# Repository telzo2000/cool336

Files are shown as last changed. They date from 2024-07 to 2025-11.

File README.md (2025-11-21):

# cool336

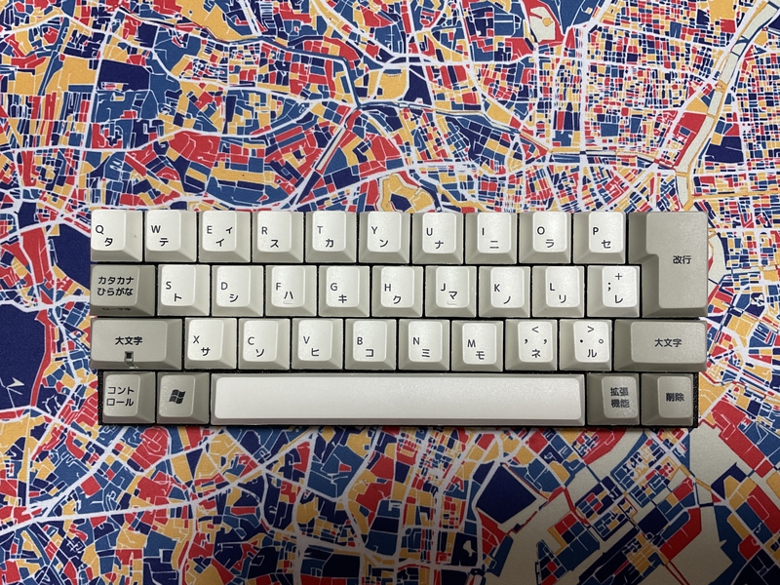
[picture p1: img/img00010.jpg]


## What is cool336?

Do you have an unused ISO enter key or 7U space key in a corner of your room?
<br>
部屋の隅に未使用の ISO エンターキーや 7U スペースキーはありませんか?
<br>
<br>
cool336 is qaz layout keyboard.
<br>
cool336はqaz配列のキーボードです。
<br><br>
cool336 has a iso enter key and 7U long space key.
<br>
cool336 には ISO Enter キーと 7U の長いスペースキーがあります。
<br>
PCV ver1.2で７Uスペースバーを３Ux2、１Ux1の三分割スペースバーの選択ができるようになりました。
<br>

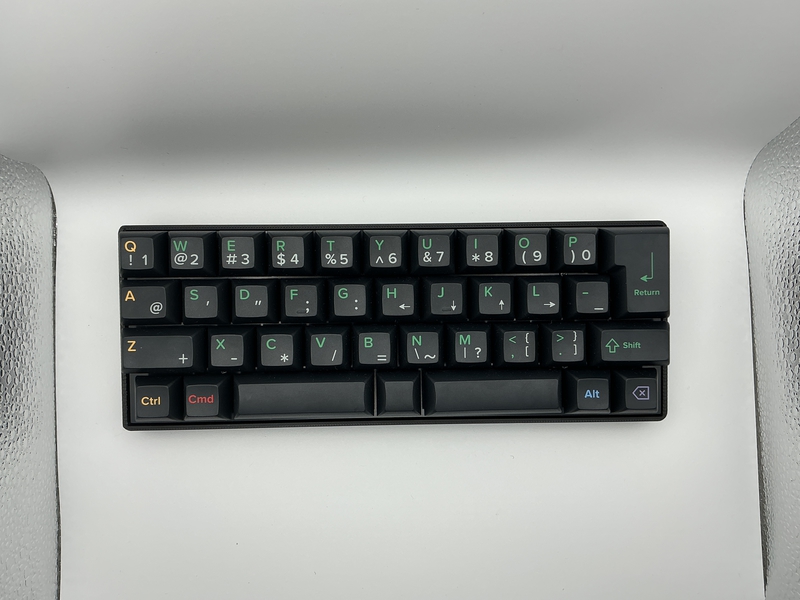
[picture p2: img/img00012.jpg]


# Layout

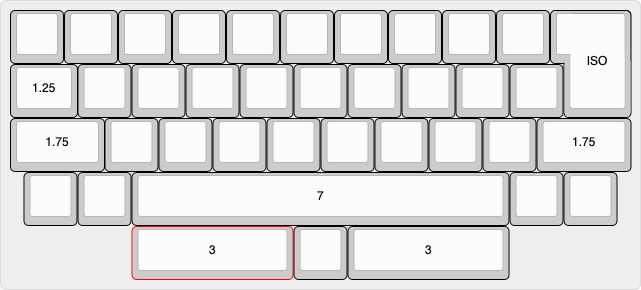
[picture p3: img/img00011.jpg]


## How to get keycaps?

https://yuzukeycaps.com/keyboards/cool336ble

## firmware 

cool336 use RP2040-Zero,run qmk_firware.
<br>
cool336 は RP2040-Zero を使用し、qmk_firware を実行します。
<br><br>

## build

### summary
1 Diode soldering
<br>
2 Switch socket soldering
<br>
3 RP2040-Zero and conthrough soldering
<br>
4 Install firmware
<br>
5 Fix thestabilizer
<br>
6 Fix the switch plate with screws
<br>
7 Insert the key switch
<br>
8 Fix the bottom plate with screws.
<br>
9 Complete
<br>

https://github.com/telzo2000/cool336/blob/main/buildguide_for_cool336.md

## Parts list

For PCB Ver.1.0
| No. | Patrs | Quantity | remarks | Suppliers | Cost |
|--|--|--|--|--|--|
|番号|名前|数|備考|調達先|参考価格（送料込）|<br>
|1|PCB|1|36key|[elecrow](https://www.elecrow.com)<br>[JLCPCB](https://jlcpcb.com)<br>[ALLPCB](https://www.allpcb.com)|５枚で20〜30ドル|<br>
|2|RP-2040Zero|1|MCU Board|[Talp Keyboard](https://talpkeyboard.net)|420円|
|3|Swith socket<br>スイッチソケット|36|cherry MX互換|[遊舎工房](https://yushakobo.jp)<br>[Talp Keyboard](https://talpkeyboard.net)<br>[Daily Craft Keyboard](https://shop.dailycraft.jp)等|10個で165円程度|
|3|Diode<br>ダイオード|36|リードタイプでもSMDでも可|[遊舎工房](https://yushakobo.jp)<br>[Talp Keyboard](https://talpkeyboard.net)<br>[Daily Craft Keyboard](https://shop.dailycraft.jp)等|100個で220円程度から|
|4a|Switch plate|1|3D Print|||
|4b|Switch plate|1|Acrylic,with M2 Spacer 3mm x4|[elecrow](https://www.elecrow.com/acrylic-cutting.html)|5枚で９ドル程度（送料込み）|
|5|Bottom plate|1|3D Print||
|6|Screw<br>ネジ|4|M2 8mm|DIY shop|10本200円程度|
|7|Screw<br>ネジ|4|M2 4mm|DIY shop|10本200円程度|
|8|Spacer<br>スペーサー|4|M2 3mm|DIY shop|10本400円程度|
|9|Stabilizer<br>スタビライザー|2|2Ux1,7Ux1|[遊舎工房](https://yushakobo.jp)<br>[Talp Keyboard](https://talpkeyboard.net)|セットで2000円程度|
|10|Conthrou<br>コンスルー|2|3.5mm|[遊舎工房](https://yushakobo.jp)<br>[Talp Keyboard](https://talpkeyboard.net)|１個400円程度|
|11|Keyswitch<br>キースイッチ|36|お好みで|[遊舎工房](https://yushakobo.jp)<br>[Talp Keyboard](https://talpkeyboard.net)<br>[Daily Craft Keyboard](https://shop.dailycraft.jp)|１個100程度|
|12|Keycap<br>キーキャップ|36|1Ux31、1.25Ux2、1.75Ux2、7Ux1|[遊舎工房](https://yushakobo.jp)<br>[Talp Keyboard](https://talpkeyboard.net)<br>[Daily Craft Keyboard](https://shop.dailycraft.jp)||

For PCB Ver.1.2
| No. | Patrs | Quantity | remarks | Suppliers | Cost |
|--|--|--|--|--|--|
|番号|名前|数|備考|調達先|参考価格（送料込）|<br>
|1|PCB|1|36key|[elecrow](https://www.elecrow.com)<br>[JLCPCB](https://jlcpcb.com)<br>[ALLPCB](https://www.allpcb.com)|５枚で20〜30ドル|<br>
|2|RP-2040Zero|1|MCU Board|[Talp Keyboard](https://talpkeyboard.net)|420円|
|3|Swith socket<br>スイッチソケット|36~38|cherry MX互換|[遊舎工房](https://yushakobo.jp)<br>[Talp Keyboard](https://talpkeyboard.net)<br>[Daily Craft Keyboard](https://shop.dailycraft.jp)等|10個で165円程度|
|3|Diode<br>ダイオード|36~38|リードタイプでもSMDでも可|[遊舎工房](https://yushakobo.jp)<br>[Talp Keyboard](https://talpkeyboard.net)<br>[Daily Craft Keyboard](https://shop.dailycraft.jp)等|100個で220円程度から|
|4|Switch plate|1|FR-4|[elecrow](https://www.elecrow.com)<br>[JLCPCB](https://jlcpcb.com)<br>[ALLPCB](https://www.allpcb.com)|５枚で20〜30ドル|
|5|Bottom Case|1|3D Print||
|6|Screw<br>ネジ|8|M2 6mm|DIY shop|10本200円程度|
|7|Spacer<br>スペーサー|4|M2 10mm|DIY shop|10本400円程度|
|8|Stabilizer<br>スタビライザー|2~3|2Ux1,7Ux1or3Ux2|[遊舎工房](https://yushakobo.jp)<br>[Talp Keyboard](https://talpkeyboard.net)|セットで2000円程度|
|10|Conthrou<br>コンスルー|2|3.5mm|[遊舎工房](https://yushakobo.jp)<br>[Talp Keyboard](https://talpkeyboard.net)|１個400円程度|
|11|Keyswitch<br>キースイッチ|36^38|お好みで|[遊舎工房](https://yushakobo.jp)<br>[Talp Keyboard](https://talpkeyboard.net)<br>[Daily Craft Keyboard](https://shop.dailycraft.jp)|１個100程度|
|12|Keycap<br>キーキャップ|36|1Ux31~32、1.25Ux2、1.75Ux2、7Ux1or3Ux2|[遊舎工房](https://yushakobo.jp)<br>[Talp Keyboard](https://talpkeyboard.net)<br>[Daily Craft Keyboard](https://shop.dailycraft.jp)||

In addition, you will need a USB cable, etc.
<br>
この他に、USBケーブル等が必要です。
<br>

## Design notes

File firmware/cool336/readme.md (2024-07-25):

# cool336

cool336

*A short description of the keyboard/project*

* Keyboard Maintainer: [m.ki](https://github.com/telzo2000)
* Hardware Supported: *The PCBs, controllers supported*
* Hardware Availability: *Links to where you can find this hardware*

Make example for this keyboard (after setting up your build environment):

    make cool336:default

Flashing example for this keyboard:

    make cool336:default:flash

See the [build environment setup](https://docs.qmk.fm/#/getting_started_build_tools) and the [make instructions](https://docs.qmk.fm/#/getting_started_make_guide) for more information. Brand new to QMK? Start with our [Complete Newbs Guide](https://docs.qmk.fm/#/newbs).

## Bootloader

Enter the bootloader in 3 ways:

* **Bootmagic reset**: Hold down the key at (0,0) in the matrix (usually the top left key or Escape) and plug in the keyboard
* **Physical reset button**: Briefly press the button on the back of the PCB - some may have pads you must short instead
* **Keycode in layout**: Press the key mapped to `QK_BOOT` if it is available

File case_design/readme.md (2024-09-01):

# About Case_design

cool336は大きく５つのパターンのケースデザインがあります。

１　3Dプリンタのスイッチプレートと3Dプリンタのボトムプレート

２　3Dプリンタのスイッチプレートと3Dプリンタのボトムケース

３　3Dプリンタのトップケースと3Dプリンタのボトムプレート

４　アクリルのスイッチプレートと3Dプリンタのボトムプレート

５　アクリルのスイッチプレートと3Dプリンタのボトムケース

１は最初に考えたサンドイッチマウントのケースです。

２はボトムプレートを修正してトレー型にしたケースです。

１及び２は[booth](https://booth.pm/ja/items/5953728)で頒布しています。

３は実験的に作ったものです。底面の合わせ目のデザインの解決がなく、使用していません。

４及び５は3Dプリントのスイッチプレートの柔らかさが気になるかなと思い、アクリルで製作したものです。[キーフリ[(https://connpass.com/event/314453/)で頒布予定です。

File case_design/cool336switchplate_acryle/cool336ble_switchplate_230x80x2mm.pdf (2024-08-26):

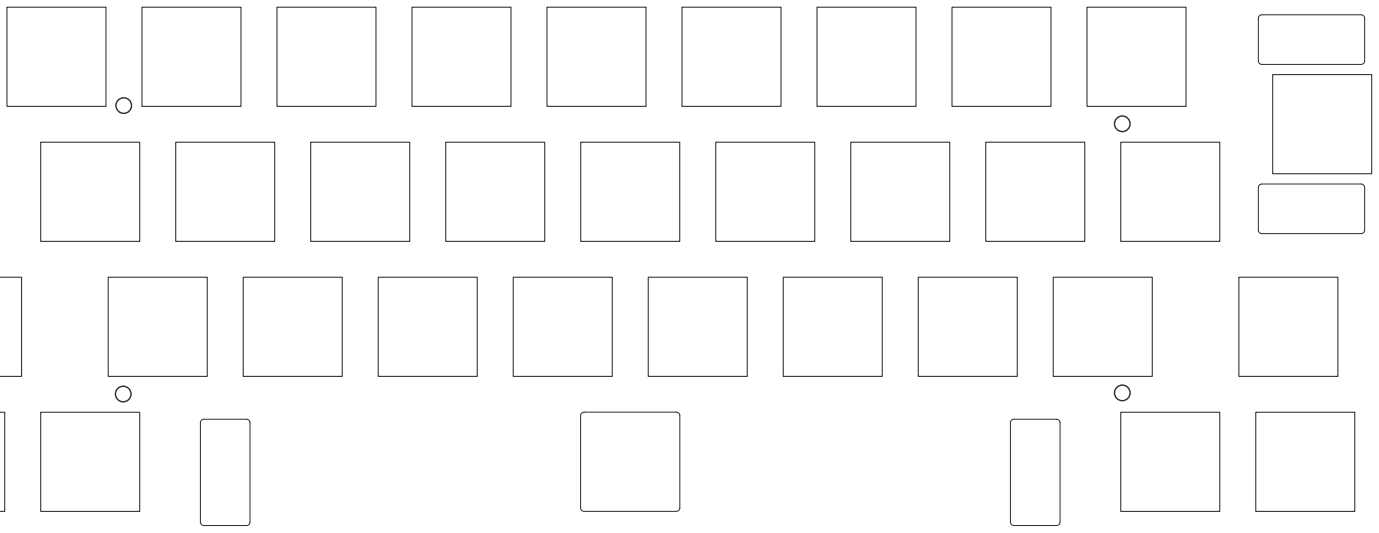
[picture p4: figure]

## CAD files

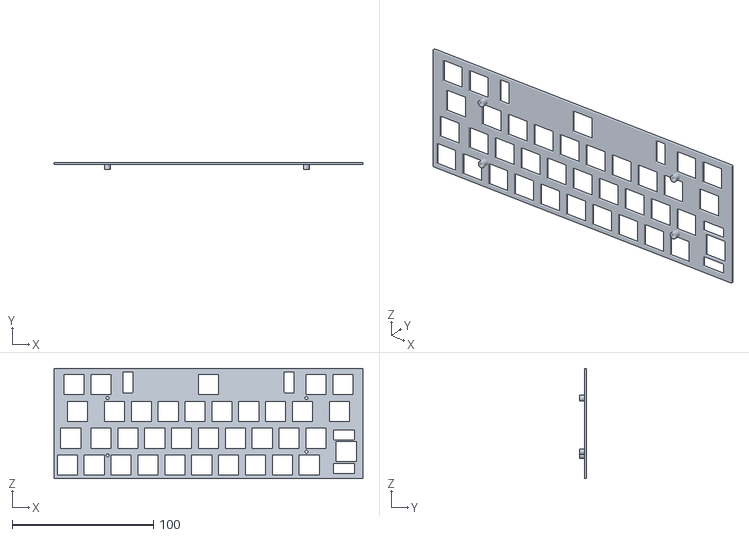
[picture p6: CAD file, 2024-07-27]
case_design/3Dprint/cool336_switchplate v6.stl
219.0 x 5.00 x 78.0

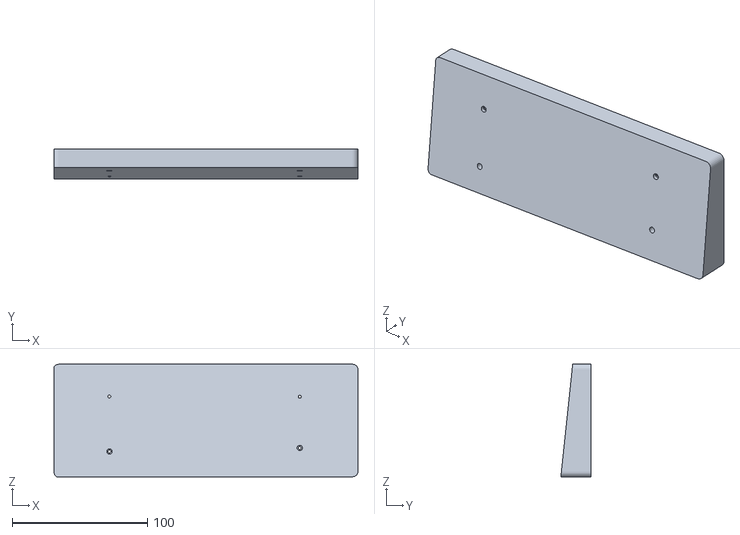
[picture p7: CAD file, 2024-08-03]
case_design/another_bottomcase_design/cool336_case_design_bottom v6.stl
225.0 x 22.4 x 83.4

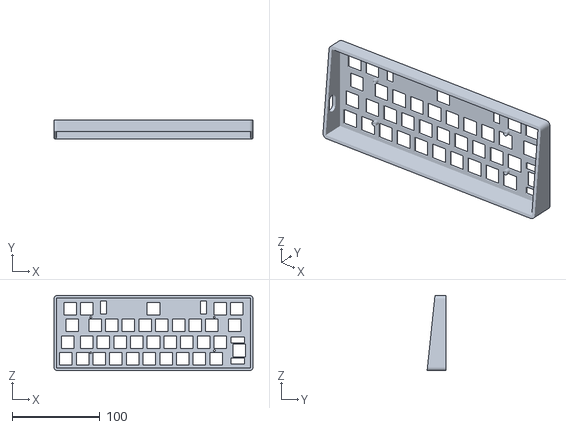
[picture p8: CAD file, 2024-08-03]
case_design/another_topcase_design/cool336_case_design v2.stl
227.0 x 21.5 x 86.0

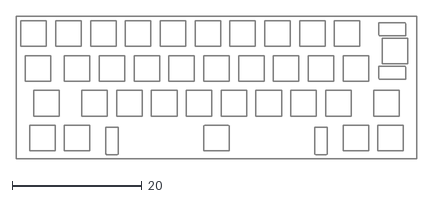
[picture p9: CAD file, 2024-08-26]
case_design/cool336switchplate_acryle/cool336ble_switchplate_230x80x2mm.dxf
61.8 x 22.0

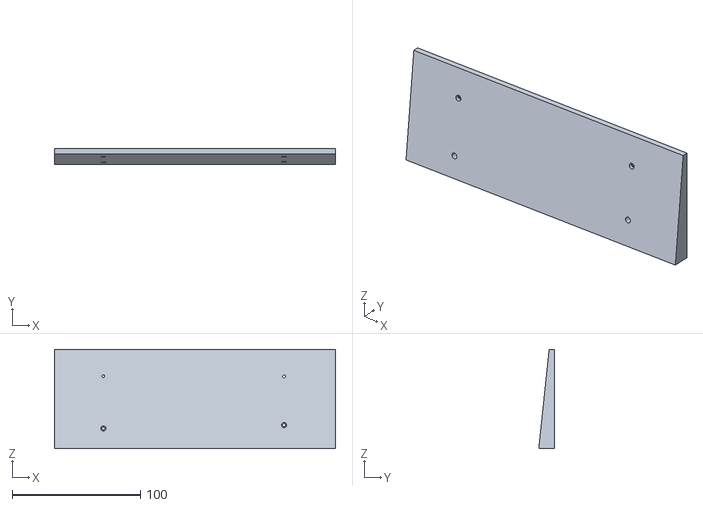
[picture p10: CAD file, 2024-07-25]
case_design/3Dprint/cool336_bottomplate v3.stl
219.1 x 12.1 x 77.4

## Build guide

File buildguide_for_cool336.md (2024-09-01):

# Build guide

## Build 1

### 1 Diode soldering

Solder the diodes to the back of PCB.
<br>
PCBの裏面にダイオードのハンダ付けをします。
<br>
There are lead type and SMD diodes.
<br>
ダイオードはリードタイプか、SMDがあります。
<br>
Here, we will explain the lead type soldering.
<br>
ここでは、リードタイプのハンダ付けの説明をします。
<br>

Use a lead bender to bend the legs of the diode.
<br>
リードベンダーを使い、ダイオードの足を曲げます。
<br>
Insert the diode into the board.
<br>
ダイオードを基板に挿しこみます。
<br>

Please pay attention to the orientation of the diode.
<br>
ダイオードの向きに注意してください。
<br>
Please solder.
<br>
はんだ付けをしてください。
<br>
<br>
Then, cut off the excess lead with nippers.
<br>
その後、余ったリードをニッパーで切り取ってください。

[８倍速　Diodeハンダ付け動画](https://youtu.be/Yaodh2-XxV4)

<br>
<br>

### 2 Switch socket soldering

Solder the switch sockets on the back side.
<br>
裏面にスイッチソケットのハンダ付けをします。
<br>

[８倍速　Switch socketハンダ付け動画](https://youtu.be/E__mHvmIXQo)

### 3 RP2040-Zero and conthrough soldering

The side on which components such as the boot button and reset button of RP-2040Zero are mounted is the front side, and the other side is the back side.
<br>
RP-2040Zeroのbootボタンやresetボタンなど部品実装されている面を表面とし、反対側を裏面とします。
<br>

Cut the conslue to the required length using nippers.
<br>
コンスルーを必要な長さにニッパーで切り分けます。
<br>
Insert the con-through along the pin hole.
<br>
コンスルーをピン穴に沿って、差し込みます。
<br>

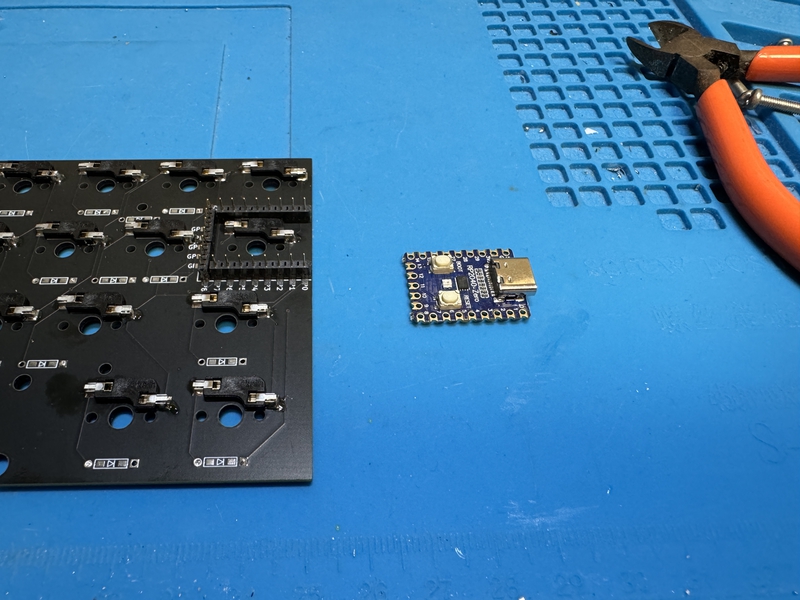
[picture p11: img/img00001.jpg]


Place RP2040-Zero there and solder it.
<br>
そこにRP2040-Zeroを合わせて、ハンダ付けをします。
<br>
<br>

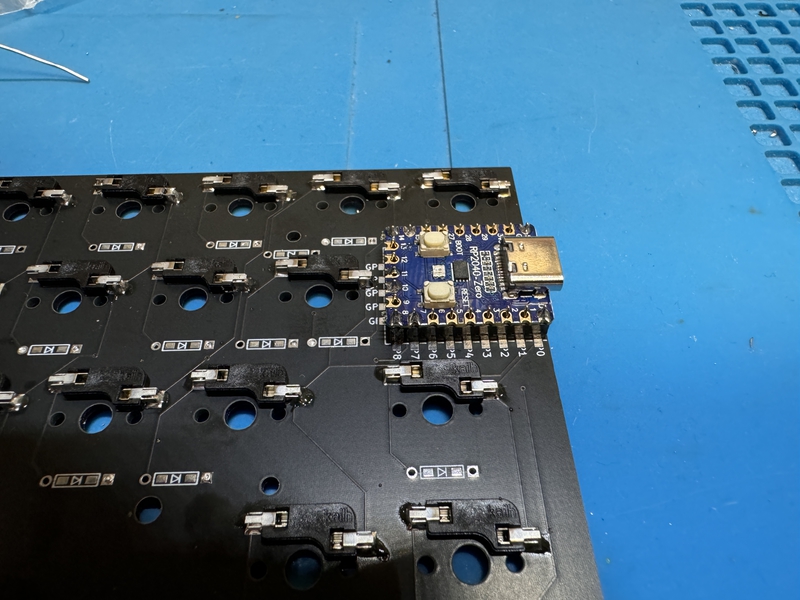
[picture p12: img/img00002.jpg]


Solder the con-through only with RP2040-Zero. PCB and con-throughs are not soldered.
<br>
コンスルーのハンダ付けはRP2040-Zeroとだけします。PCBとコンスルーはハンダ付けしません。
<br>
<br>

### 4 Install firmware

Install QMK_Firmware from your PC to RP-2040Zero.
<br>
QMK_FirmwareをPCからRP-2040Zeroにインストールしてください。
<br>
<br>
① Download https://github.com/telzo2000/cool336/blob/main/firmware/cool336_vial.uf2 to your PC.
<br>
① https://github.com/telzo2000/cool336/blob/main/firmware/cool336_vial.uf2　
をPCにダウンロードしておく。

<br><br>
② Connect the PC and RP-2040Zero with a USB cable.
<br>
②PCとRP-2040ZeroをUSBケーブルで繋ぐ。
<br><br>
③Press the reset button while pressing the boost button on the RP-2040Zero.
<br>
③RP-2040Zeroのboostボタン押しながら、resetボタンを押す。
<br><br>
④Since there is a folder of RP-2040Zero on the PC screen, drag and drop the downloaded cool336_vial.uf2 there.
<br>
④PC画面にはRP-2040Zeroのフォルダがあるので、そこに、ダウンロードしたcool336_vial.uf2をドラッグアンドドロップする。
<br><br>

⑤Check if it is recognized by connecting to [vial](https://get.vial.today/). Edit the keymap accordingly.
<br>
⑤[vial](https://get.vial.today/)に繋いで認識するかどうか確認する。合わせてキーマップの編集をする。

### 5 Fix the stabilizer

Attach the stabilizer to the surface of the PCB.
<br>
PCBの表面にスタビライザーを装着してください。
<br>

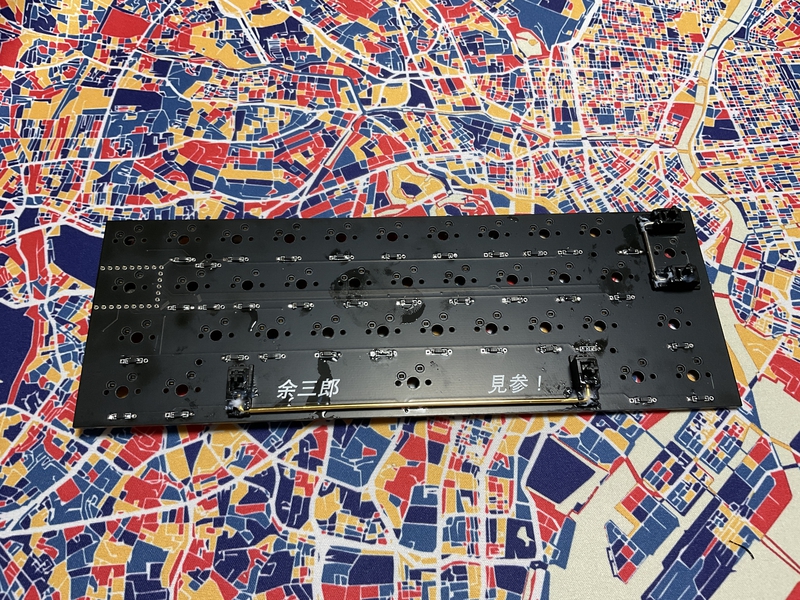
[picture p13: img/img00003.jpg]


The stabilizer will operate smoothly if it is greased.
<br>
スタビライザーはグリスをしておくと、滑らかに稼働します。
<br>
<br>

### 6a Fix the switch plate(3D Print) with screws

Place the 3D printed switch plate on the surface of the PCB.
<br>
3Dプリンタで印刷されたスイッチプレートをPCBの表面に載せます。
<br>

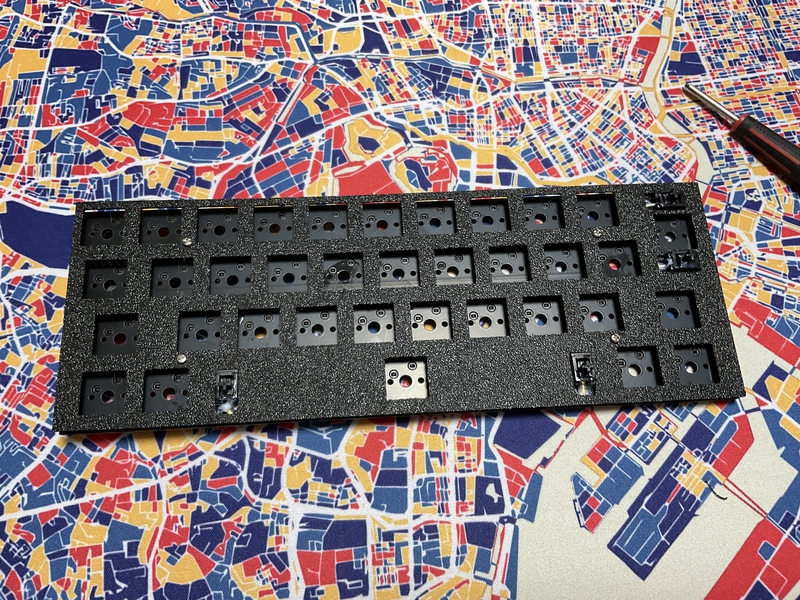
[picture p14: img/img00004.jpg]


Insert four M2 screws (8mm) from the surface and secure with M2 spacers (3mm) on the back side of the PCB.
<br>
表面からM2ネジ（8mm）を４本挿して、PCB裏側でM2スペーサー（3mm）で固定してください。
<br>

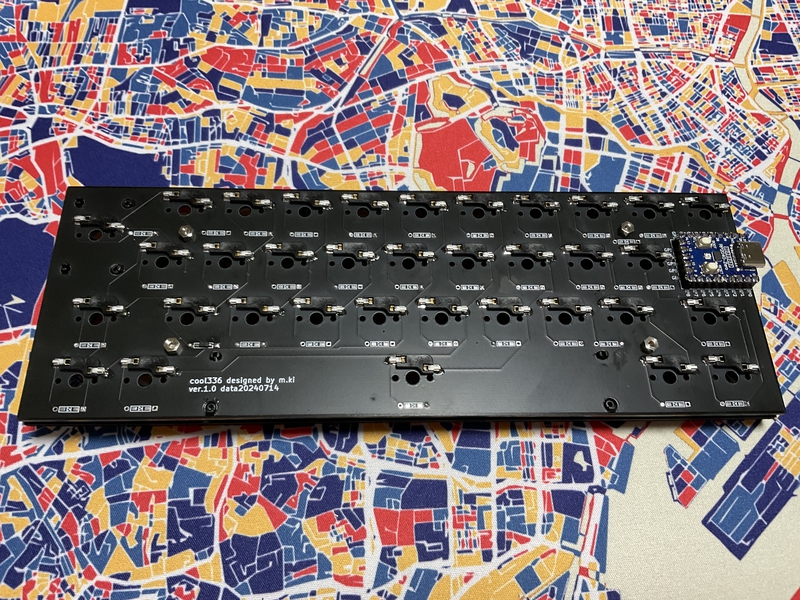
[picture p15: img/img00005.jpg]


### 6b Fix the switch plate(Acrylic) with screws

Insert the acrylic switch plate, the M2 spacer (3mm), and the M2 screw (8mm) in that order to secure it.
<br>
アクリルのスイッチプレート、M2スペーサー（3mm）の順でM2ネジ（8mm）の順で差し込んで固定します。
<br><<br>
Place the switch plate on the surface of the PCB.
<br>
スイッチプレートをPCBの表面に載せます。
<br><br>
Fix it with M2 spacer (3mm) on the back side of the PCB.
<br>
PCB裏側でM2スペーサー（3mm）で固定してください。
<br><br>

### 7 Insert the key switch

Insert the key switch from the switch plate side.
<br>
スイッチプレート側からキースイッチを差し込んでいきます。
<br>
<br>
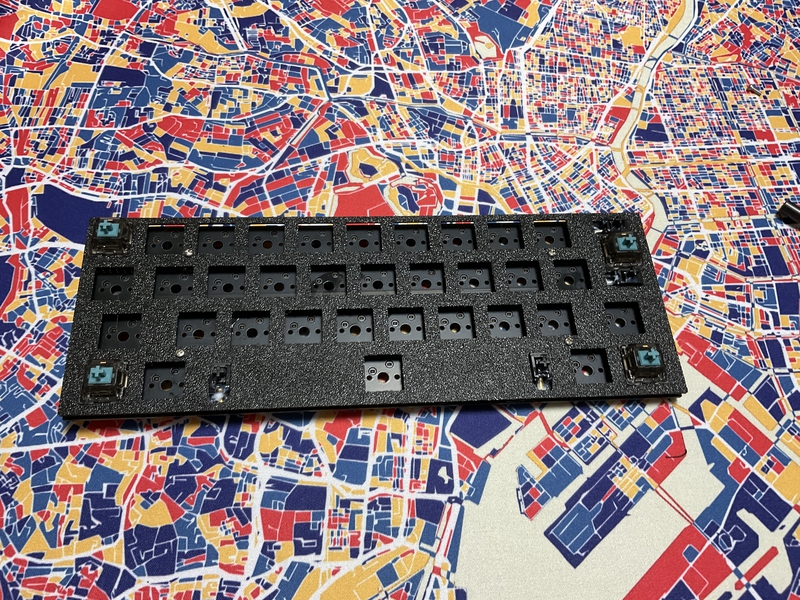
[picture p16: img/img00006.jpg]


Due to the characteristics of the switch plate printed with a 3D printer, the square hole of the key switch may be tight. In that case, use a cutter or other bladed tool to scrape off the burr inside the square hole.
<br>
スイッチプレートは3Dプリンタで印刷した特性により、もしかしたら、キースイッチの四角穴がきついことがあります。その時は、カッターなど刃物で四角穴内側のバリを削り取ってください。
<br>

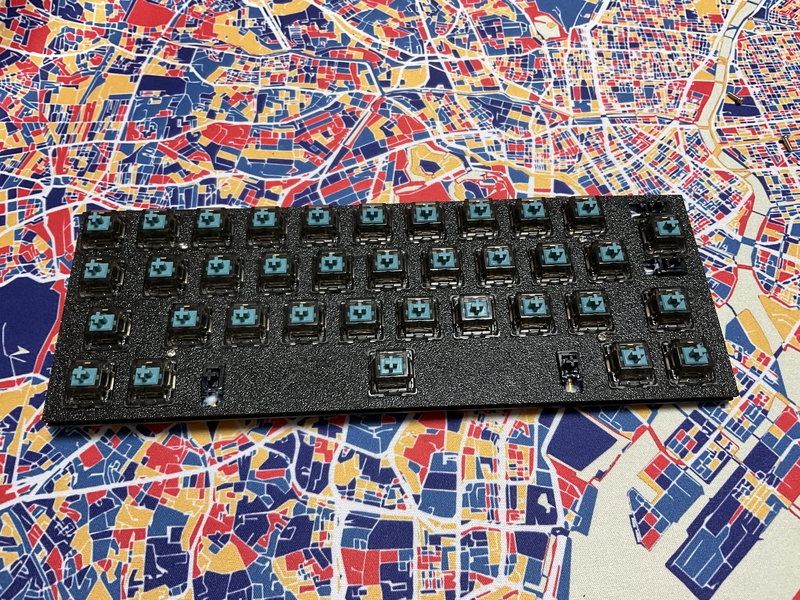
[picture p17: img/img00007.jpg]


### 8a Fix the bottom plate with screws

With the PCB facing backwards, secure the bottom plate with four M2 screws (4mm). There is a recess with a diameter of 5 mm and a depth of about 1 mm on the top surface of the bottom plate. Make sure that the M2 spacer fits there.
<br>
PCBを裏側にして、ボトムプレートをM2ネジ（4mm）４本で固定してください。ボトムプレートの上面には1mmほどの深さの直径5mmの凹部があります。そこに、M2スペーサーがはまるようにしてください。
<br>
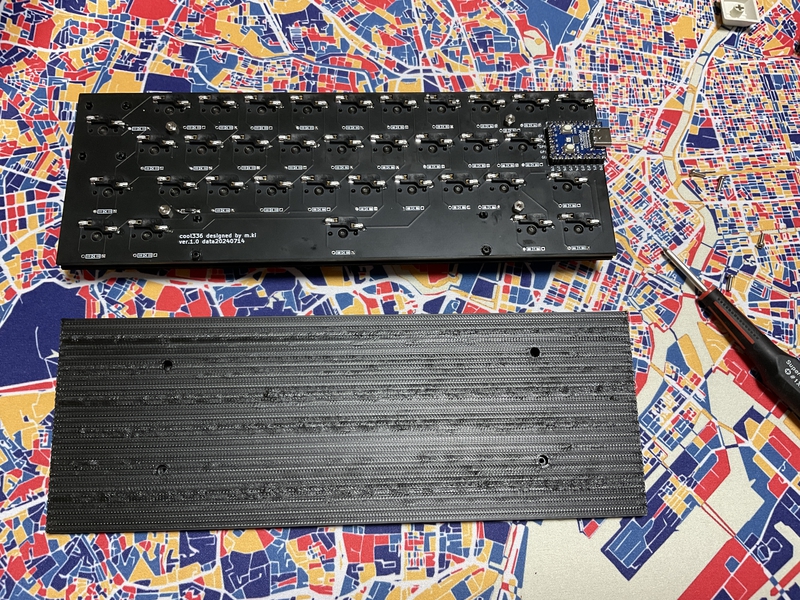
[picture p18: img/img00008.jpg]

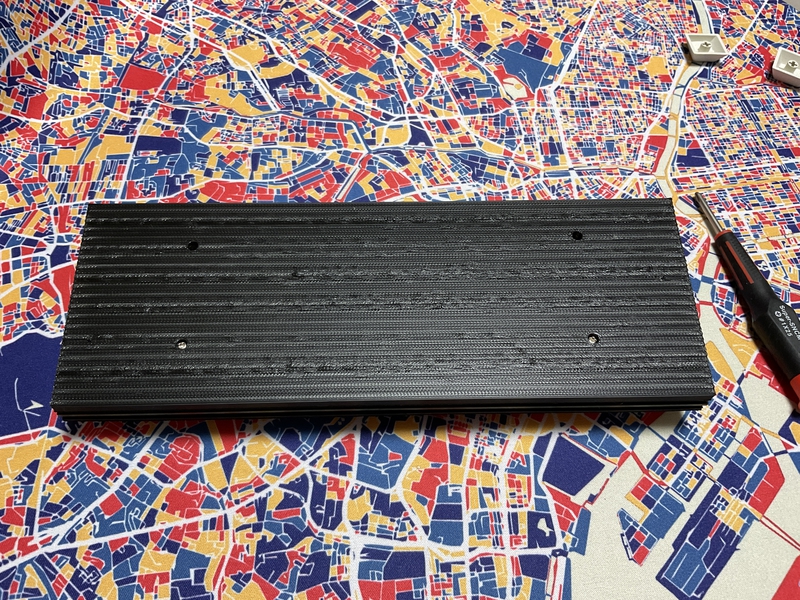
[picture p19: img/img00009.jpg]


### 8b Fix the bottom case with screws

PCBを裏側にして、ボトムケースをM2ネジ（4mm）４本で固定してください。ボトムプレートの上面には1mmほどの深さの直径5mmの凹部があります。そこに、M2スペーサーがはまるようにしてください。
<br>

<br>
To prevent the RP2040-Zero from falling inside the case when the cable is connected or disconnected, we recommend placing the enclosed sponge under the USB insertion slot.
<br>
ケーブルの抜き差しにより、RP2040-Zeroがケース内部で落下することを防ぐため、同封したスポンジをUSB挿入口の下につけることを推奨します。
<br>
<br>

### 9 Complete

Attach your favorite keycaps and you're done.
<br>
お気に入りのキーキャップをつけて完成です。
<br>


<br>
Welcome to the world of the best keyboards.
<br>
最高のキーボードの世界にようこそ。
<br>
